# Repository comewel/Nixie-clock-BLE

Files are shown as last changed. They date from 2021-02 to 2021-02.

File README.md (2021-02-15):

# Nixie-clock-BLE
Project inspired by [GreatScott!](https://www.youtube.com/watch?v=ObgmVNV1Kfg)'s video. The main difference is in the MCU choice, in this project it is used the ESP32 to give the Nixie clock the change of time capabilities with bluetooth.

## PCB looks like
#### Front:
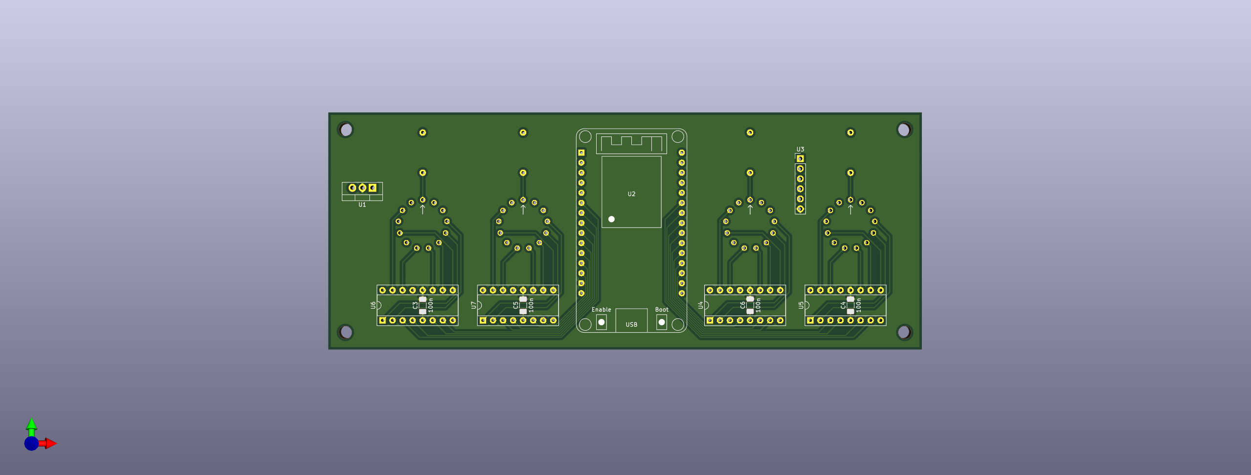
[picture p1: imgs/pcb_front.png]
Front

#### Back:
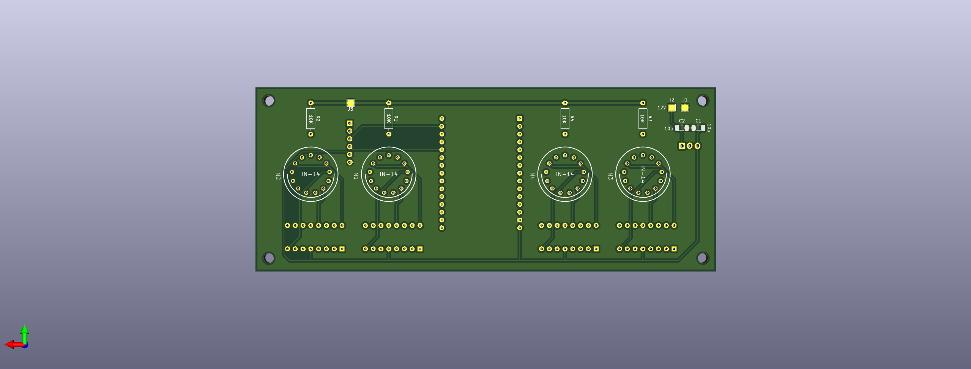
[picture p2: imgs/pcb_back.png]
Back

## List of components

The raw list
- 1 x ESP32 
- 4 x Nixie clock tube (IN-14 type)
- 4 x Nixie clock driver
- 1 x RTC (In the project it was used the DS 3231 shield)
- 1 x Boost converter (in order to get the 170V required by the nixie tubes)
- 1 x Voltage regulator (In the project it was used an L7805CV)
- 2 x 10uF capacitors (for the 12V and 5V lines)
- 4 x 100nF capacitors (one for each nixie driver)
- 4 x 10K Resistors (one between each nixie clock's anode and 170V)
Should be it.

## The firmware
The only piece that is required to fill is the `NIXIE_CLOCK_SERVICE_UUID` definition.

## 3D printing design files
Inside the folder `3D-case-design` there are the AutoDesk Fusion 360 design files used for this project in `.stl` and `.f3d` format.
Click [here](./3D-case-design/case.stl) for a preview of the case design.

:exclamation:  Please notice that the lid is slightly off. We have made only a simple draft and then decided to leave it as it was (see notes below).

## Notes
1. In the current project the majority of components are in the same side of the Nixie tubes. This will prevent the use of a top flat cover, unless you decide to put a lot of holes in it.
So all the components should be moved on the back side and rearranging the connection in accordance.
2. The nixie clock tubes used for the hour and the one used for the minutes are not symmetrical to the center of the PCB.

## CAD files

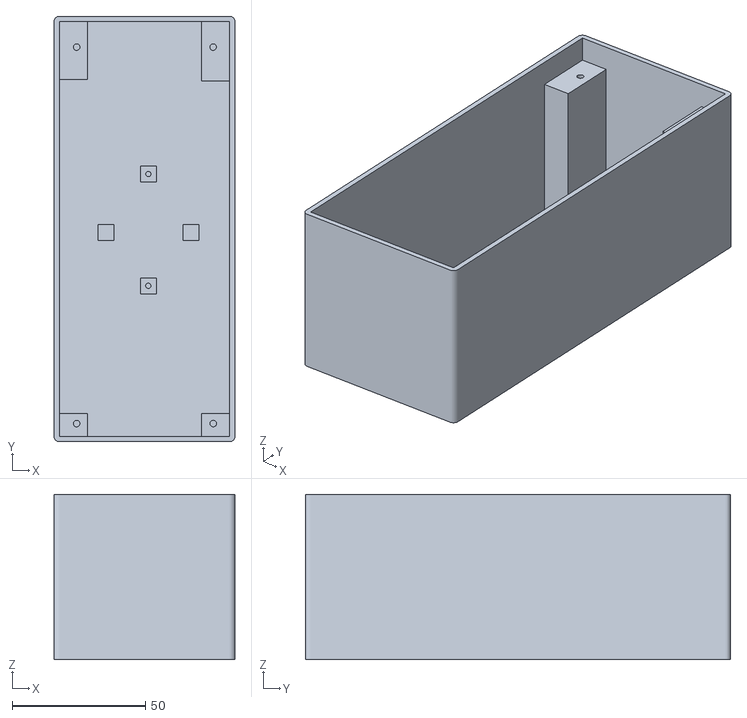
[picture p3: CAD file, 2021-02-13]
3D-case-design/case.stl
68.0 x 159.8 x 62.0

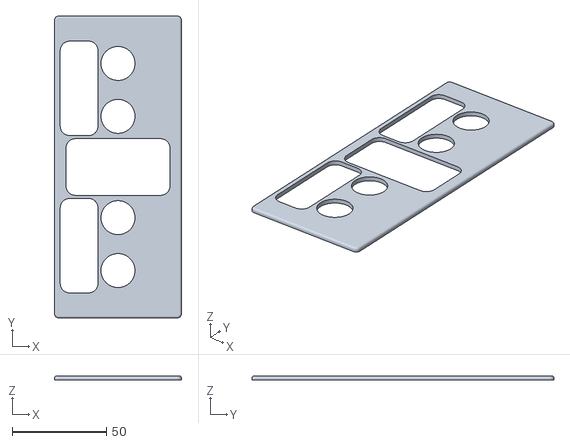
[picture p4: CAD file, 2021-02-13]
3D-case-design/lid.stl
67.2 x 159.8 x 2.22

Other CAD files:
3D-case-design/case.f3d
3D-case-design/lid.f3d

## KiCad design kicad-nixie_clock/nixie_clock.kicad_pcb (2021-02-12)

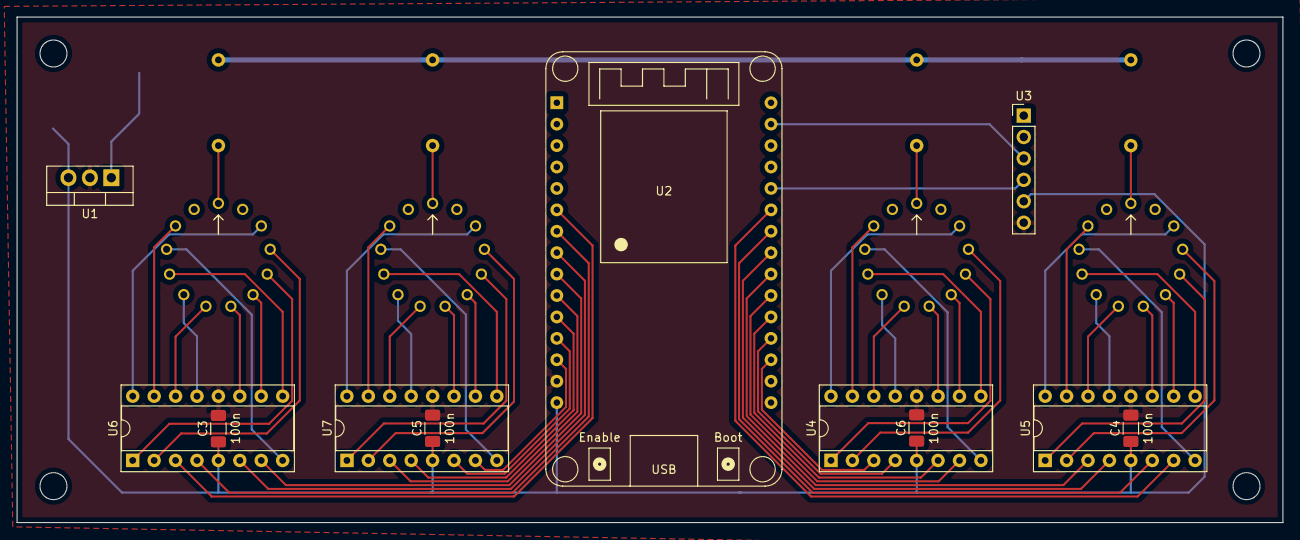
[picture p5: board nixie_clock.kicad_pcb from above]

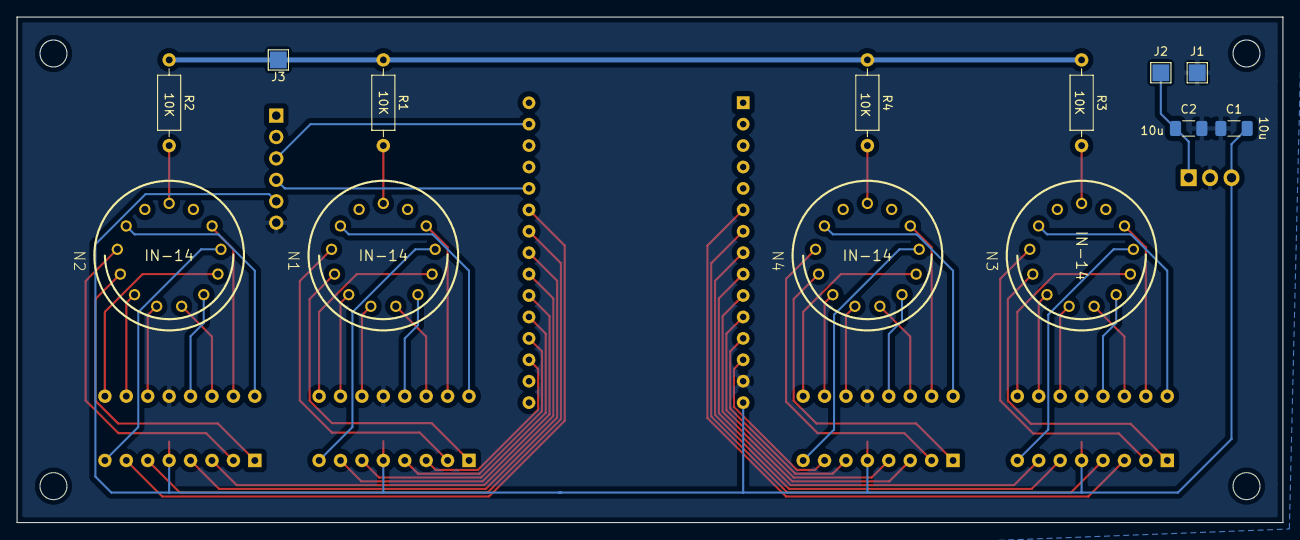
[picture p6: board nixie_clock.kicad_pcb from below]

Board: 2 copper layers, 150.1 x 59.9 mm, 24 parts (13 on the bottom side), 66 nets.

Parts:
C1, C2: 10u; C_1206_3216Metric_Pad1.33x1.80mm_HandSolder
C3, C4, C5, C6: 100n; C_1206_3216Metric_Pad1.33x1.80mm_HandSolder
J1: GND; TestPoint_Pad_2.0x2.0mm
J2: 12V; TestPoint_Pad_2.0x2.0mm
J3: 170V; TestPoint_Pad_2.0x2.0mm
N1, N2, N3, N4: IN-14; nixies-us-IN-14
R1, R2, R3, R4: 10K; R_Axial_DIN0207_L6.3mm_D2.5mm_P10.16mm_Horizontal
U1: LM7805_TO220; TO-220-3_Vertical
U2: ESP32_DevKit_V1_DOIT; footprints_esp32_devkit_v1_doit.pretty_esp32_devkit_v1_doit
U3: RTC-devkit; PinHeader_1x06_P2.54mm_Vertical
U4, U5, U6, U7: K155ID1; DIP-16_W7.62mm_Socket

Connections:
+5V: C1.1, C3.1, C4.1, C5.1, C6.1, U1.3, U2.15, U3.5, U4.5, U5.5, U6.5, U7.5
+12V: C2.1, J2.1, U1.1
/+170: J3.1, R1.1, R2.1, R3.1, R4.1
/A1: U2.18, U4.3
/A2: U2.22, U5.3
/A3: U2.6, U6.3
/A4: U2.10, U7.3
/B1: U2.20, U4.6
/B2: U2.24, U5.6
/B3: U2.8, U6.6
/B4: U2.12, U7.6
/C1: U2.21, U4.7
/C2: U2.25, U5.7
/C3: U2.9, U6.7
/C4: U2.13, U7.7
/D1: U2.19, U4.4
/D2: U2.23, U5.4
/D3: U2.7, U6.4
/D4: U2.11, U7.4
GND: C1.2, C2.2, C3.2, C4.2, C5.2, C6.2, J1.1, U1.2, U2.14, U3.6, U4.12, U5.12, U6.12, U7.12
unnamed: N1.0, U4.16
unnamed: N1.1, U4.15
unnamed: N1.2, U4.8
unnamed: N1.3, U4.9
unnamed: N1.4, U4.13
unnamed: N1.5, U4.14
unnamed: N1.6, U4.11
unnamed: N1.7, U4.10
unnamed: N1.8, U4.1
unnamed: N1.9, U4.2
unnamed: N1.A, R1.2
unnamed: N2.0, U5.16
unnamed: N2.1, U5.15
unnamed: N2.2, U5.8
unnamed: N2.3, U5.9
unnamed: N2.4, U5.13
unnamed: N2.5, U5.14
unnamed: N2.6, U5.11
unnamed: N2.7, U5.10
unnamed: N2.8, U5.1
unnamed: N2.9, U5.2
unnamed: N2.A, R2.2
unnamed: N3.0, U6.16
unnamed: N3.1, U6.15
unnamed: N3.2, U6.8
unnamed: N3.3, U6.9
unnamed: N3.4, U6.13
unnamed: N3.5, U6.14
unnamed: N3.6, U6.11
unnamed: N3.7, U6.10
unnamed: N3.8, U6.1
unnamed: N3.9, U6.2
unnamed: N3.A, R3.2
unnamed: N4.0, U7.16
unnamed: N4.1, U7.15
unnamed: N4.2, U7.8
unnamed: N4.3, U7.9
unnamed: N4.4, U7.13
unnamed: N4.5, U7.14
unnamed: N4.6, U7.11
unnamed: N4.7, U7.10
unnamed: N4.8, U7.1
unnamed: N4.9, U7.2
unnamed: N4.A, R4.2
unnamed: U2.26, U3.4
unnamed: U2.29, U3.3

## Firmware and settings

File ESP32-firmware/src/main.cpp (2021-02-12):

#include <Arduino.h>
#include <BLEDevice.h>
#include <BLEUtils.h>

#include "RTClib.h"

// See the following for generating UUIDs:
// https://www.uuidgenerator.net/

#define NIXIE_CLOCK_SERVICE_UUID "USE ^ AND FILL HERE"

#define A1 15
#define B_1 4 // B1 is already defined
#define C1 16
#define D1 2

#define A2 17
#define B2 18
#define C2 19
#define D2 5

#define A3 32
#define B3 25
#define C3 26
#define D3 33

#define A4 27
#define B4 12
#define C4 13
#define D4 14

#define HOUR_ONE 2
#define HOUR_TWO 3

#define MINUTES_ONE 0
#define MINUTES_TWO 1

uint8_t nixie_map[4][4] = {
    {A1, B_1, C1, D1},
    {A2, B2, C2, D2},
    {A3, B3, C3, D3},
    {A4, B4, C4, D4},
};

BLECharacteristic *nixieCharacteristic;

// RTC DS3231
RTC_DS3231 rtc;

// BLUETOOTH
// ###########################################################################################

class NixieServerCallbacks : public BLEServerCallbacks
{
  void onConnect(BLEServer *pServer)
  {
    Serial.println("connect");
  };

  void onDisconnect(BLEServer *pServer)
  {
    Serial.println("disconnect");
  }
};

class ManageClockCharacteristic : public BLECharacteristicCallbacks
{
  // expect string like hh:mm

  void onWrite(BLECharacteristic *pCharacteristic) override
  {
    uint8_t hour;
    uint8_t minutes;

    std::string new_time = pCharacteristic->getValue();
    Serial.print("Received: ");
    Serial.println(new_time.c_str());

    uint32_t res = sscanf(new_time.c_str(), "%hhu:%hhu", &hour, &minutes);

    if (res != 2 || hour > 24 || minutes > 60)
    {
      return;
    }
    DateTime now = rtc.now();
    rtc.adjust(DateTime(now.year(), now.month(), now.day(), hour, minutes));

    Serial.println("New time\t");
    Serial.print(hour);
    Serial.print(":");
    Serial.println(minutes);
  }

  void onRead(BLECharacteristic *pCharacteristic) override
  {
    Serial.println("reading value from service");
    DateTime now = rtc.now();

    char *time_now;
    int32_t res = asprintf(&time_now, "%hhu:%hhu", now.hour(), now.minute());
    if (res == -1)
    {
      Serial.println("Error allocating the space for the current time...");
      return;
    }

    pCharacteristic->setValue(time_now);
    pCharacteristic->notify();
    free(time_now);
  }
};

void init_BLE()
{
  Serial.println("Starting BLE server!");

  BLEDevice::init("Nixie-clock");
  BLEServer *nixieServer = BLEDevice::createServer();
  nixieServer->setCallbacks(new NixieServerCallbacks()); // maybe usefull?

  BLEService *pService = nixieServer->createService(NIXIE_CLOCK_SERVICE_UUID);

  nixieCharacteristic = pService->createCharacteristic(
      NIXIE_CLOCK_SERVICE_UUID,
      BLECharacteristic::PROPERTY_READ |
          BLECharacteristic::PROPERTY_WRITE |
          BLECharacteristic::PROPERTY_NOTIFY);

  nixieCharacteristic->setCallbacks(new ManageClockCharacteristic());

  pService->start();

  BLEAdvertising *pAdvertising = BLEDevice::getAdvertising();
  pAdvertising->addServiceUUID(NIXIE_CLOCK_SERVICE_UUID);
  pAdvertising->setScanResponse(true);
  pAdvertising->setMinPreferred(0x06); // functions that help with iPhone connections issue
  pAdvertising->setMinPreferred(0x12);
  pAdvertising->start();

  Serial.println("Characteristic defined! Now you can read and write it from your phone!");
}

// ###########################################################################################

// RTC
void init_RTC()
{
  if (rtc.lostPower())
  {
    Serial.println("RTC lost power, let's set the time!");
    // When time needs to be set on a new device, or after a power loss, the
    // following line sets the RTC to the date & time this sketch was compiled
    rtc.adjust(DateTime(F(__DATE__), F(__TIME__)));
  }
}

// ###########################################################################################

void set_nixie_value(uint8_t nixie_position, uint8_t value)
{
  uint8_t *nixie_cur = nixie_map[nixie_position];
  
  for (uint8_t nixie_pin = 0; nixie_pin < 4; nixie_pin++)
  {
    uint8_t current_multiplexer_value = (value >> nixie_pin) & 0x01;
    digitalWrite(nixie_cur[nixie_pin], current_multiplexer_value);
  }
}

void init_Nixie()
{
  for (uint8_t nixie_pos = 0; nixie_pos < 4; nixie_pos++)
  { // only 4 nixie :)
    for (uint8_t nixie_pin = 0; nixie_pin < 4; nixie_pin++)
    { // 4 input per multiplexer
      pinMode(nixie_map[nixie_pos][nixie_pin], OUTPUT);
      digitalWrite(nixie_map[nixie_pos][nixie_pin], LOW);
    }
  }
}
void test_nixie()
{
  uint8_t value_to_show = 0;
  while (true)
  {
    for (uint8_t nixie_pos = 0; nixie_pos < 4; nixie_pos++)
    {
      set_nixie_value(nixie_pos, value_to_show % 10);
    }
    value_to_show = (1 + value_to_show) % 10;
    delay(500);
  }
}
// ###########################################################################################
void setup()
{
  Serial.begin(57600);

  if (!rtc.begin())
  {
    Serial.println("Couldn't find RTC");
    Serial.flush();
    abort();
  }
  init_RTC();
  init_BLE();

  init_Nixie();

  // use test_nixie only to check the integrity of the nixie tubes
  // test_nixie();
}

void loop()
{
  DateTime now = rtc.now();

  uint8_t hour = now.hour();
  uint8_t minutes = now.minute();

  set_nixie_value(HOUR_ONE, hour / 10);
  set_nixie_value(HOUR_TWO, hour % 10);

  set_nixie_value(MINUTES_ONE, minutes / 10);
  set_nixie_value(MINUTES_TWO, minutes % 10);

  delay(500);
}

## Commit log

2021-02-12 add esp32 firmware
2021-02-12 add kicad project
    [nixie_clock-B_Cu.gbl, nixie_clock-B_Mask.gbs, nixie_clock-B_SilkS.gbo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]
2021-02-13 3D printing design files added
    [case.f3d, case.stl, lid.f3d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]
